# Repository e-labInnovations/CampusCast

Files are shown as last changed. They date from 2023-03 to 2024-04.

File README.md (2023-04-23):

<p align="center">
  <a href="http://campuscast.elabins.com/">
    CampusCast Logo
  </a>
</p>

<p align="justify">
CampusCast is an IoT-based announcement system designed to improve communication within academic institutions. The system consists of hardware and software components, including a microcontroller, digital-to-analogue converter, power amplifier, acknowledgement button, backend IoT server, WebSocket technology, and mobile app. With CampusCast, teachers and authorities can send voice announcements with customizable routes to specific classrooms, branches, years, or classes, ensuring every message is received and acknowledged. The system also includes features such as Smart Notifications and Exam Time Alerts to provide targeted and timely communication without disrupting class activities. CampusCast aims to modernize the communication system in colleges and universities, enhance the campus experience for everyone involved, and improve student engagement and academic success.
</p>

- [CampusCast Mobile APP](https://github.com/e-labInnovations/CampusCast-app)
- [CampusCast Server](https://github.com/e-labInnovations/CampusCast-server)

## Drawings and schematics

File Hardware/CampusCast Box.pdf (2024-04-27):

# CampusCast CampusCast

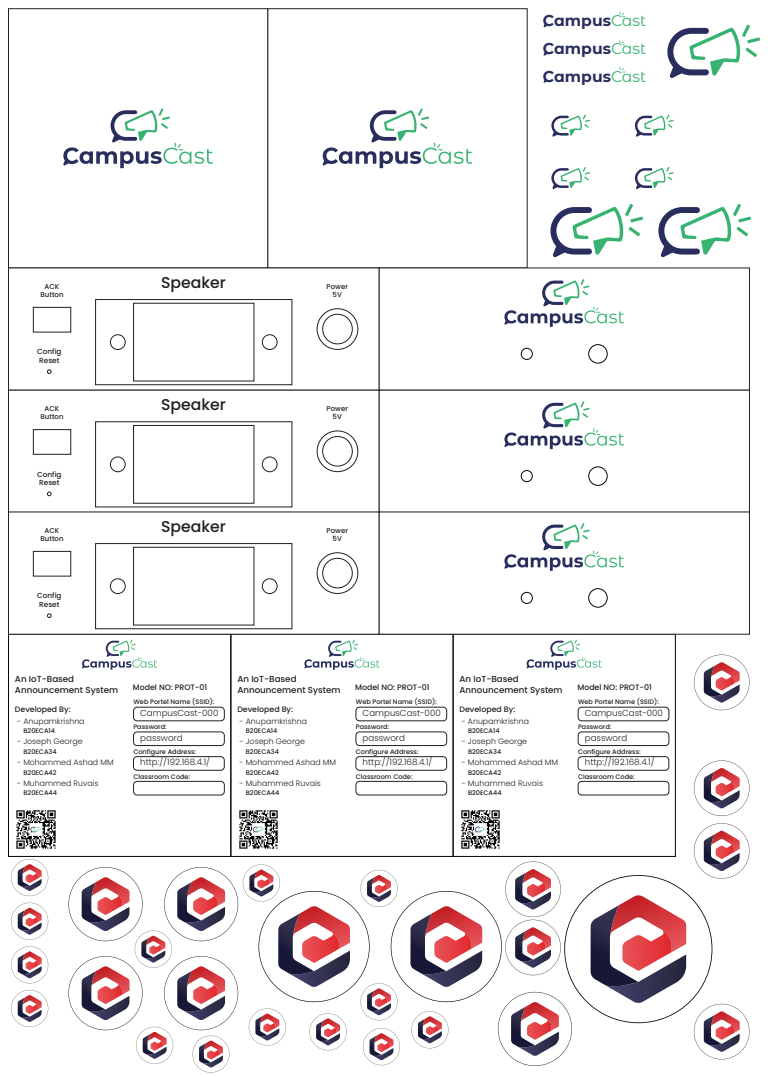
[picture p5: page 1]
Config Reset; ACK; Speaker Button; Power 5V; CampusCast; Developed By: - Anupamkrishna B20ECA14 - Joseph George B20ECA34 - Mohammed Ashad MM B20ECA42 - Muhammed Ruvais B20ECA44; An IoT-Based Announcement System

Model NO: PROT-01
Web Portel Name (SSID):
CampusCast-000
Password:
password
Configure Address:
http://192.168.4.1/
Classroom Code:

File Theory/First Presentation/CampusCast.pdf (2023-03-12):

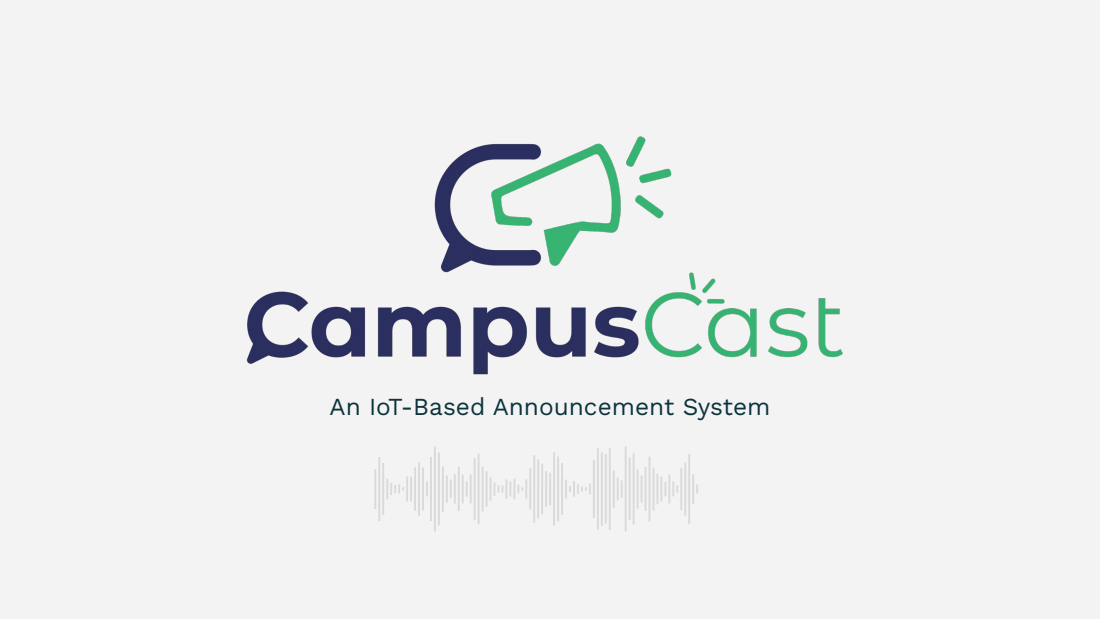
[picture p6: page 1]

An IoT-Based Announcement System

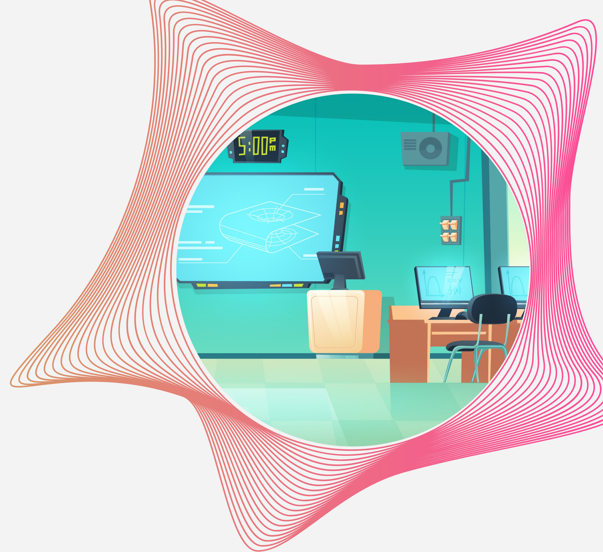
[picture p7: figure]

Welcome to CampusCast, an IoT-based announcement system that offers a modern and efficient solution for communication within academic institutions. With this system, college authorities can easily send voice announcements with customizable routes to specific classrooms, branches, years, or classes. CampusCast helps save time and resources by providing a targeted and timely communication channel, while also keeping students and faculty informed about important updates and events.

# Introduction

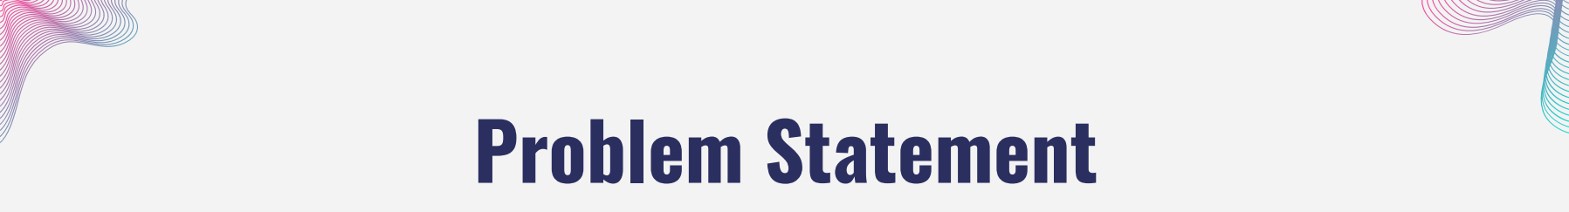
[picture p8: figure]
Problem Statement

1. In many colleges, teachers send announcements or important messages through WhatsApp groups while students are attending classes. However, it can be difficult for students to check their smartphones and receive timely notifications while in class.
2. Some students rely on hostel WiFi to access WhatsApp messages, but many colleges do not provide WiFi on campus, making it challenging for students to stay connected and receive important updates.
3. During exams, the bell system often favors regular classes, leaving students taking exams without proper time alerts. Even if they have smartwatches, these devices are not allowed in classrooms.

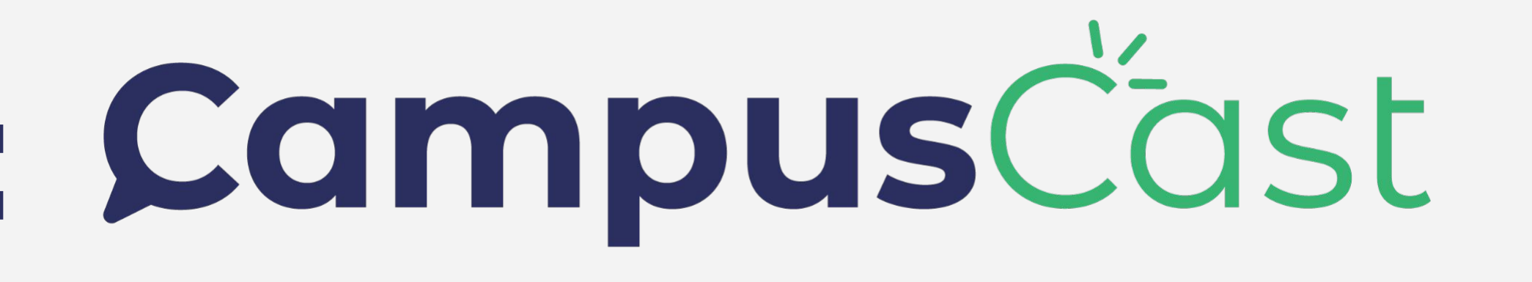
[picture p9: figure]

# Our Solution:

Revolutionizing Campus Communication

- CampusCast is an IoT-based announcement system that revolutionizes campus communication by providing a smart and efficient way for teachers and students to stay connected.
- With CampusCast , teachers can send announcements, reminders, and important messages to students instantly through a centralized system that ensures every message is received and acknowledged.
- CampusCast provides a feature called "Smart Notification" that ensures students receive important messages at the right time, without interrupting their class activities. This feature allows students to receive notifications via a smart speaker, without having to check their smartphones.

# Our Solution:

Revolutionizing Campus Communication

- CampusCast also provides a feature called "Exam Time Alerts" that sends notifications to students attending exams, ensuring they are informed about exam times. This feature helps to eliminate the need for the traditional bell system, which can be disruptive to exam-taking students.
- With CampusCast, students can also receive messages and announcements even if they don't have access to Wi-Fi on campus. The system uses IoT technology that ensures messages are delivered with the acknowledgement.
- CampusCast is easy to use and user-friendly, allowing you to send announcements quickly and easily, similar to sending a snap on the Snapchat app.

# Hardware System

+=

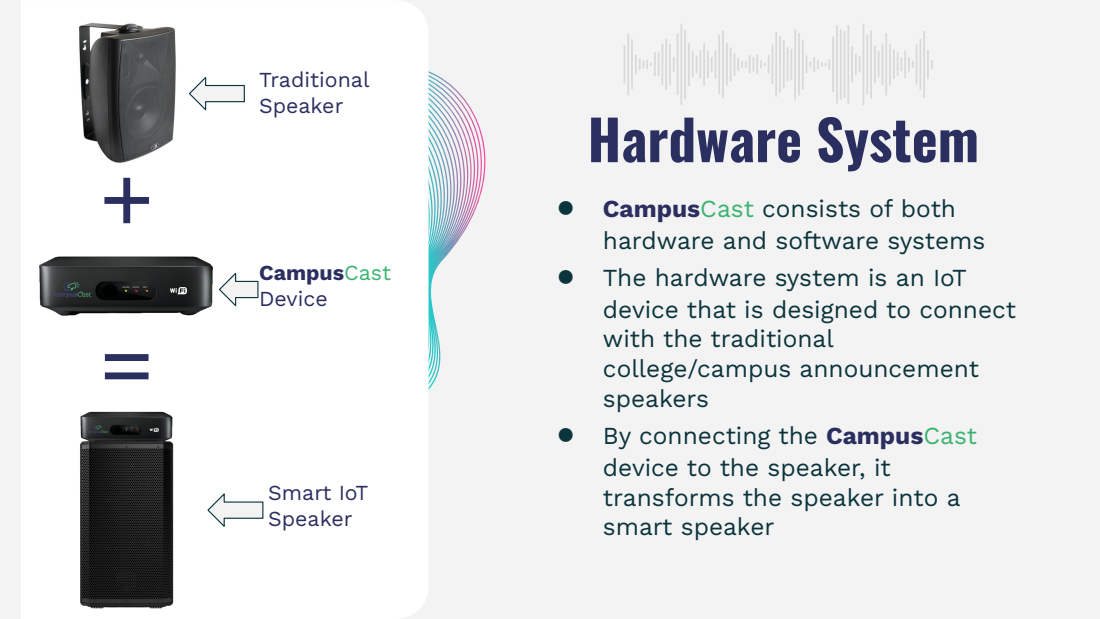
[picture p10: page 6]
Traditional Speaker; CampusCast Device; Smart IoT Speaker

● CampusCast consists of both
hardware and software systems
● The hardware system is an IoT
device that is designed to connect
with the traditional
college/campus announcement
speakers
● By connecting the CampusCast
device to the speaker, it
transforms the speaker into a
smart speaker

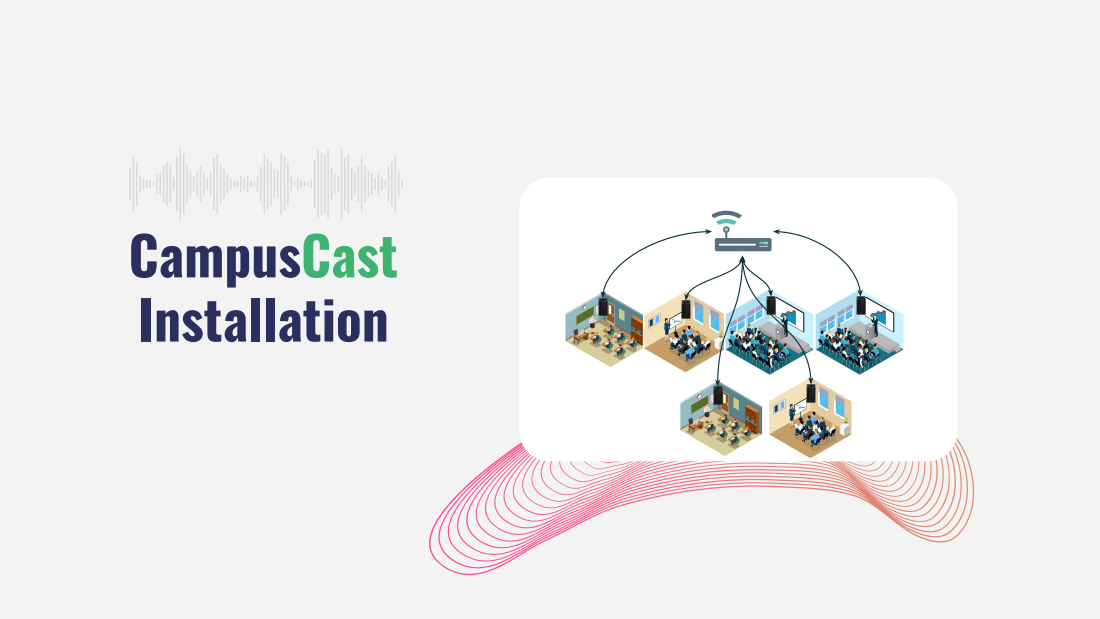
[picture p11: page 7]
CampusCast Installation

# CampusCast System Architecture

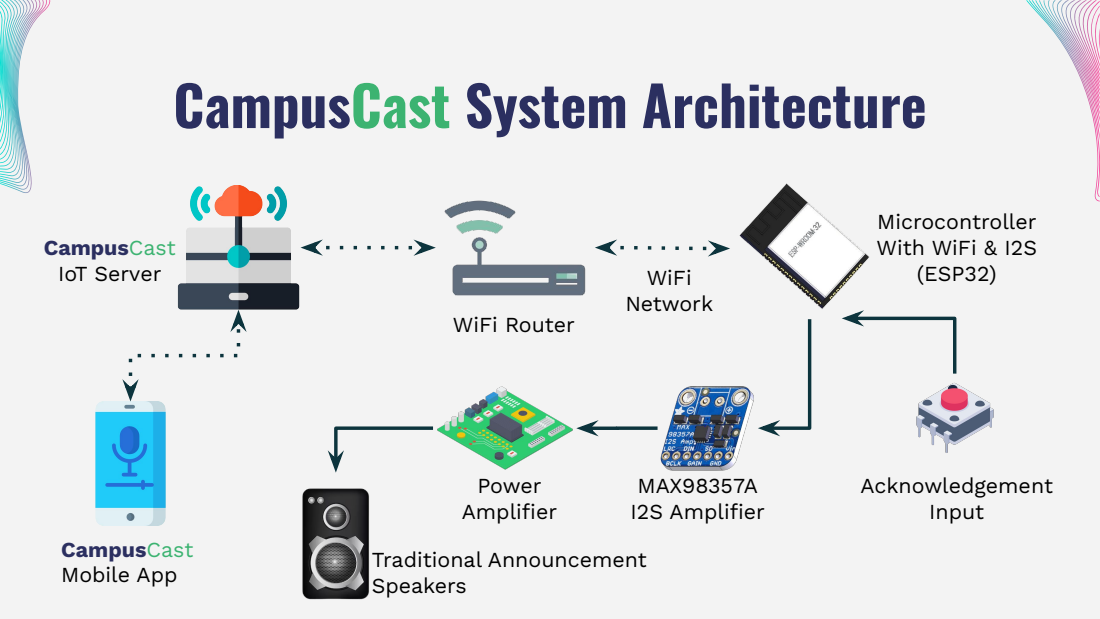
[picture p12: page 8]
Traditional Announcement Speakers; CampusCast Mobile App; Power Amplifier; MAX98357A I2S Amplifier; Acknowledgement Input; WiFi Router; IoT Server; WiFi; Network

Microcontroller With WiFi & I2S | (ESP32)

CampusCast

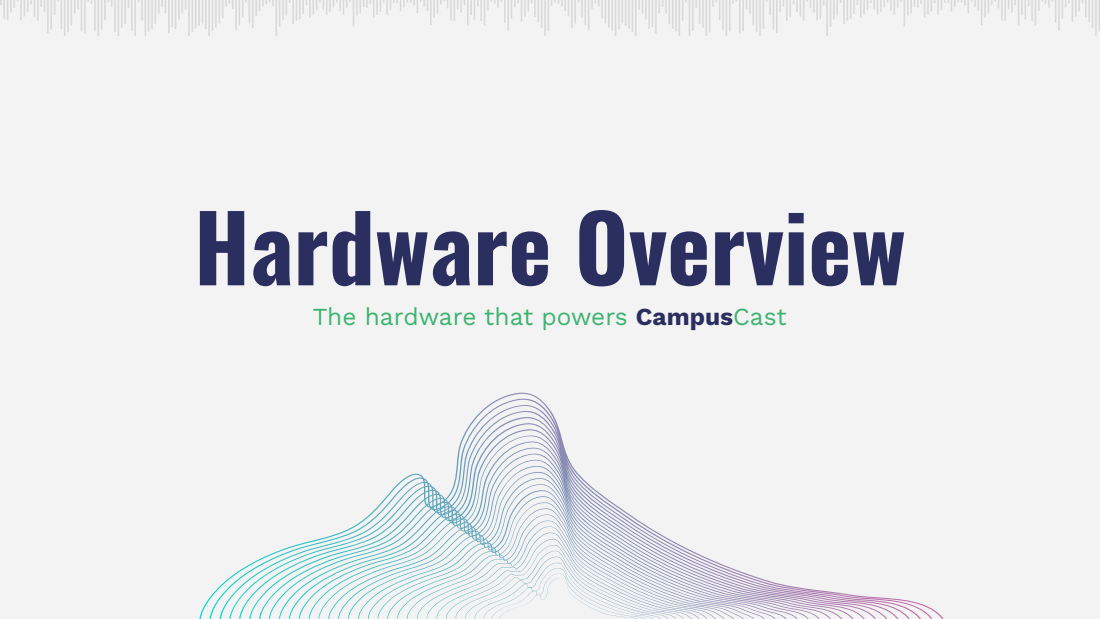
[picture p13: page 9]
Hardware Overview

The hardware that powers CampusCast

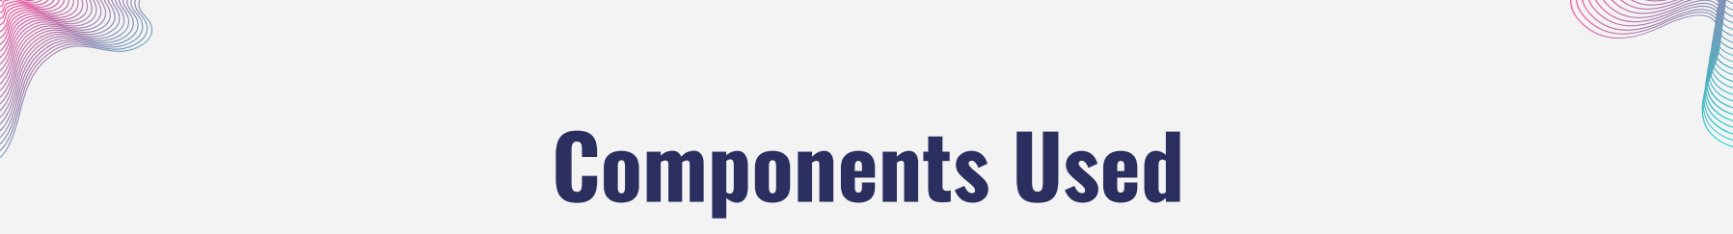
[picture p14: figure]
Components Used

1. ESP32: A powerful microcontroller that serves as the brain of the CampusCast system.
2. MAX98357A I2S Amplifier: A digital-to-analog converter that converts the audio signals from the ESP32 into an analog signal.
3. Class D Power Amplifier: An amplifier that amplifies the analog signal from the MAX98357A and provides enough power to drive the college wall mount speakers.
4. Acknowledgement Button: A button that allows the students to acknowledge that they have received a message or announcement. This helps ensure that important information is not missed.

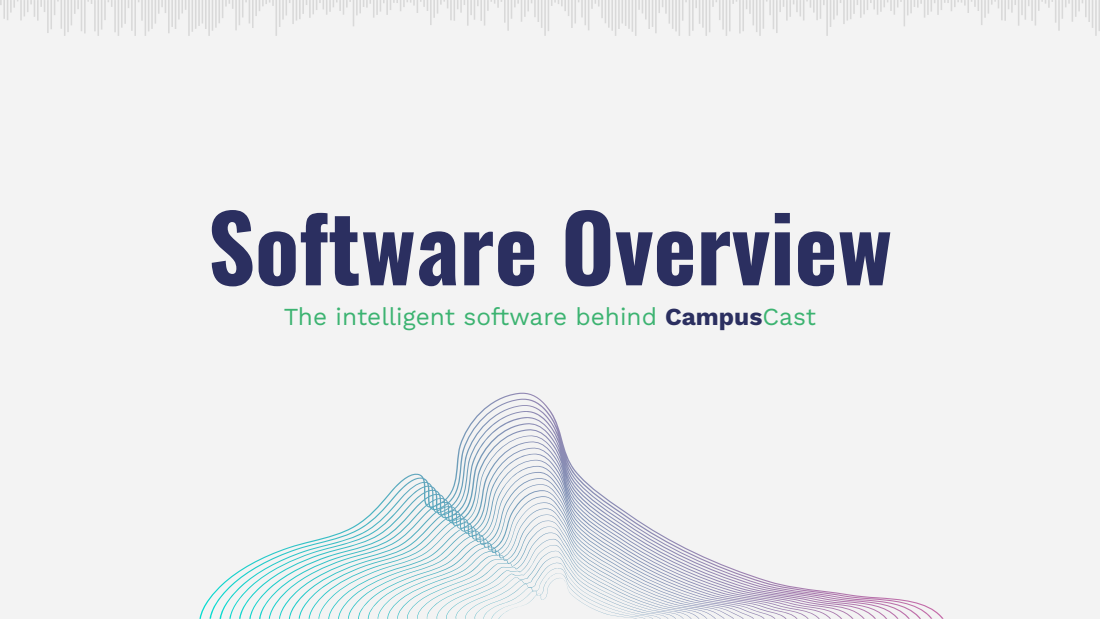
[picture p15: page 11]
Software Overview

The intelligent software behind CampusCast

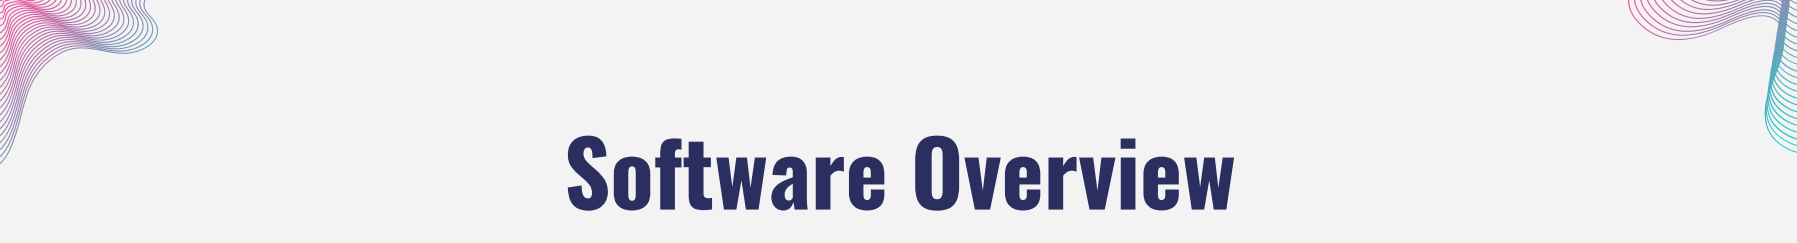
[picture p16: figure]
Software Overview

1. Backend IoT server: Planning to use Node-RED or Node.js for the backend IoT server that will handle the communication between the CampusCast devices and the mobile app.
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






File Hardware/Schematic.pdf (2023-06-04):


Drawn By: Mohammed Ashad

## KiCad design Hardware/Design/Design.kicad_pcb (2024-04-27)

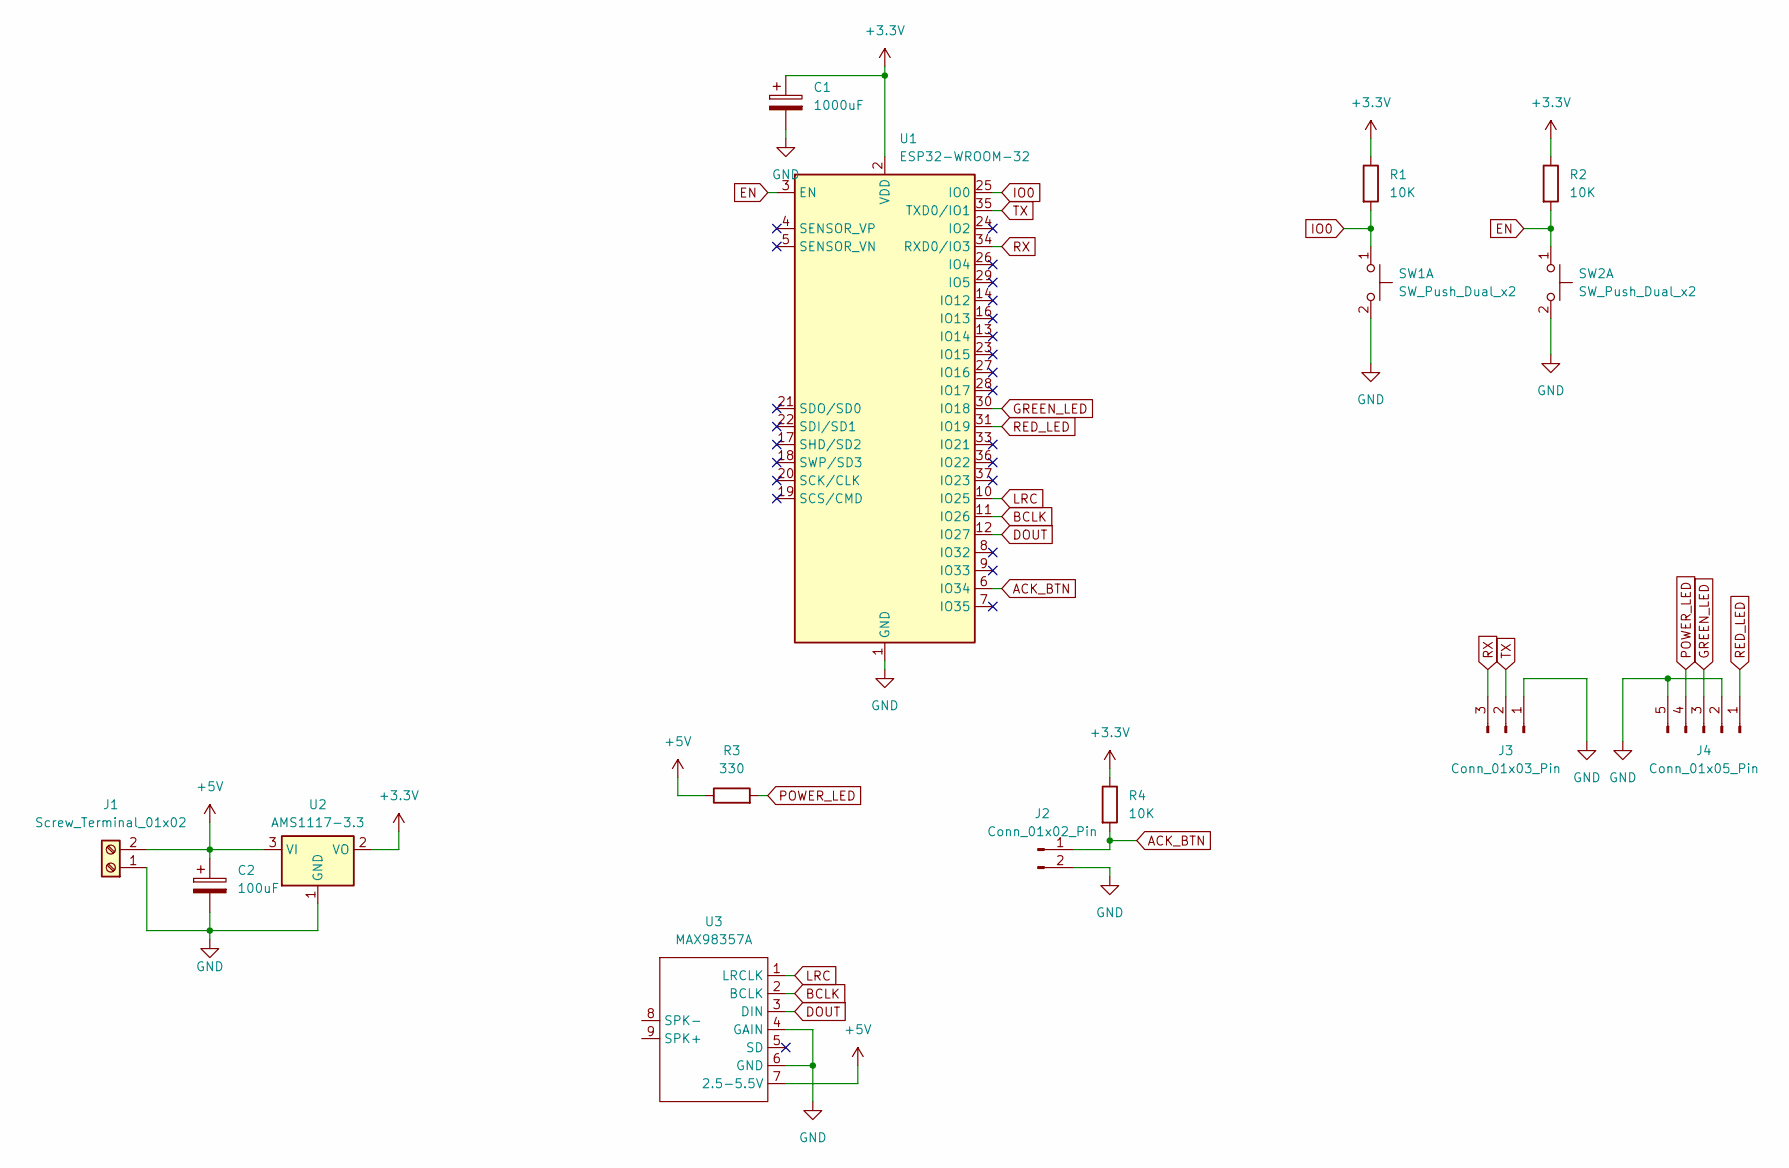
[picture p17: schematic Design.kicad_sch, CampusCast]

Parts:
C1: 1000uF; CP_Radial_D8.0mm_P5.00mm
C2: 100uF; CP_Radial_D5.0mm_P2.00mm
J1: Screw_Terminal_01x02; TerminalBlock_Phoenix_MKDS-1,5-2-5.08_1x02_P5.08mm_Horizont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
J2: Conn_01x02_Pin; PinHeader_1x02_P2.54mm_Vertical
J3: Conn_01x03_Pin; PinHeader_1x03_P2.54mm_Vertical
J4: Conn_01x05_Pin; PinHeader_1x05_P2.54mm_Vertical
R1, R2, R4: 10K; R_Axial_DIN0207_L6.3mm_D2.5mm_P7.62mm_Horizontal
R3: 330; R_Axial_DIN0207_L6.3mm_D2.5mm_P7.62mm_Horizontal
SW1, SW2: SW_Push_Dual_x2; SW_PUSH_6mm_H7.3mm
U1: ESP32-WROOM-32; ESP32-WROOM-32_MOD
U2: AMS1117-3.3; SOT-223-3_TabPin2
U3: MAX98357A

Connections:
+3.3V: C1.1, R1.1, R2.1, R4.1, U1.2 (VDD), U2.2 (VO)
+5V: C2.1, J1.2, R3.1, U2.3 (VI), U3.7 (2.5-5.5V)
ACK_BTN: J2.1, R4.2, U1.6 (IO34)
BCLK: U1.11 (IO26), U3.2 (BCLK)
DOUT: U1.12 (IO27), U3.3 (DIN)
EN: R2.2, SW2.1 (C), U1.3 (EN)
GND: C1.2, C2.2, J1.1, J2.2, J3.1, J4.2, J4.5, SW1.2 (D), SW2.2 (D), U1.1 (GND), U1.15 (GND), U1.38 (GND), U1.39 (GND), U2.1 (GND), U3.4 (GAIN), U3.6 (GND)
GREEN_LED: J4.3, U1.30 (IO18)
IO0: R1.2, SW1.1 (C), U1.25 (IO0)
LRC: U1.10 (IO25), U3.1 (LRCLK)
POWER_LED: J4.4, R3.2
RED_LED: J4.1, U1.31 (IO19)
RX: J3.3, U1.34 (RXD0/IO3)
TX: J3.2, U1.35 (TXD0/IO1)

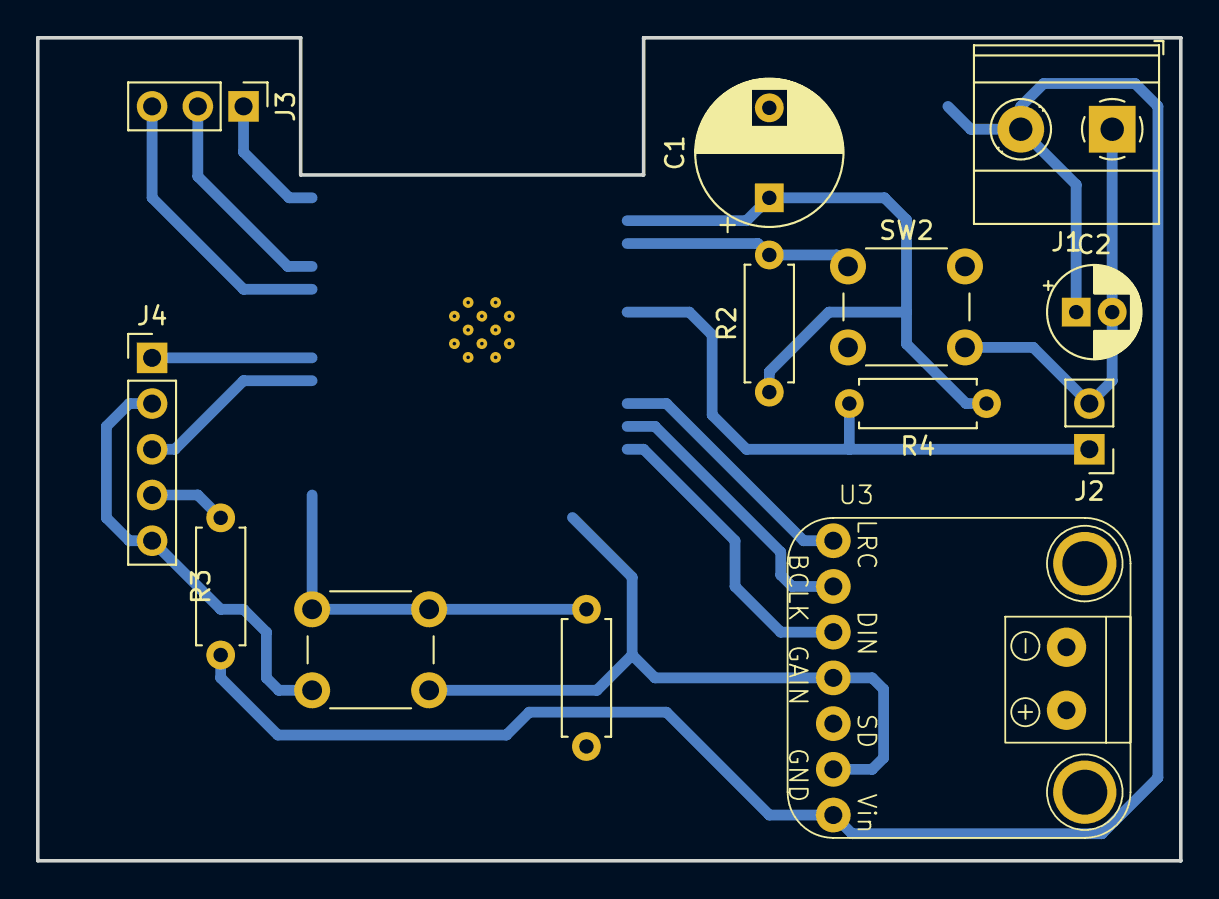
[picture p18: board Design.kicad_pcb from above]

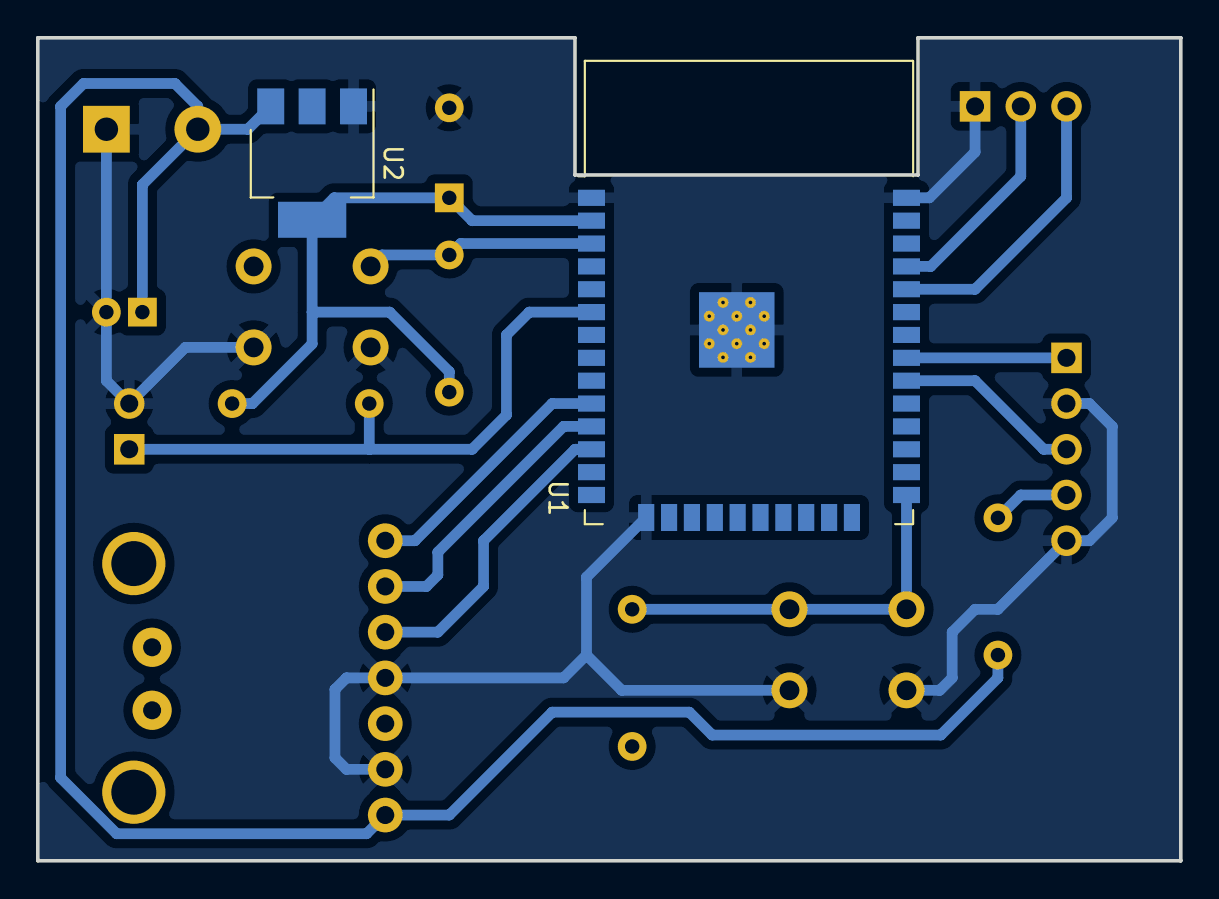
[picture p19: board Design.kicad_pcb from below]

Board: 2 copper layers, 63.5 x 45.7 mm, 15 parts (2 on the bottom side), 14 nets.

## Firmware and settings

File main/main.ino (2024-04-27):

#include <FS.h>  // this needs to be first, or it all crashes and burns...
#include <SPIFFS.h>
#include "./src/WiFiManager/WiFiManager.h"
#include <ArduinoJson.h>       // https://github.com/bblanchon/ArduinoJson
#include <WebSocketsClient.h>  //version 2.3.6
#include "WiFi.h"
#include "Audio.h"
/*
ESP32 Board             => 2.0.13
FS                      => 2.0.0  
SPIFFS                  => 2.0.0
WiFi                    => 2.0.0
Update                  => 2.0.0
WebServer               => 2.0.0
DNSServer               => 2.0.0
ArduinoJson             => 6.20.1 
WebSockets              => 2.3.6
WiFiClientSecure        => 2.0.0
ESP32-audioI2S-master   => 2.0.0
SPI                     => 2.0.0
SD                      => 2.0.0
SD_MMC                  => 2.0.0
FFat                    => 2.0.0
*/

#define SSID_PREFIX "CampusCast_"
#define PASSWORD "password"
#define JSON_CONFIG_FILE "/config.json"

#define I2S_DOUT 27
#define I2S_BCLK 26
#define I2S_LRC 25
#define BTN_CONFIG_RESET 0
#define BTN_ACK 34
#define RED_LED 19
#define GREEN_LED 18

Audio audio;
WiFiManager wm;
WebSocketsClient webSocket;

bool shouldSaveConfig = true;
char classroom_code_val[10] = "000";
char ws_server_val[21] = "192.168.x.x";
int ws_server_port_val = 1880;
char ws_server_path_val[41] = "/";

bool playAudio = false;
String audioURL = "";
String anncmntId = "";
bool prevAckStatus = true;
String introURL = "";
String outroURL = "";
int audioStatus = 0;
String audioType = "";

enum IndicatorStatus {
  START_MODE,
  CONFIG_MODE,
  WIFI_NOT_CONN,
  WIFI_CONN_SRV_NOT_CONN,
  WIFI_SRV_OK
};

struct Indicator {
  int redLedOldStatus;
  int greenLedOldStatus;
  IndicatorStatus currentStatus;
  unsigned long previousMillis;
};
Indicator indicator;


void setup() {
  Serial.begin(115200);
  Serial.setDebugOutput(true);

  audio.setPinout(I2S_BCLK, I2S_LRC, I2S_DOUT);
  audio.setVolume(21);

  pinMode(BTN_CONFIG_RESET, INPUT);
  pinMode(BTN_ACK, INPUT);

  pinMode(RED_LED, OUTPUT);
  pinMode(GREEN_LED, OUTPUT);

  // Initialize the Indicator structure
  indicator.redLedOldStatus = LOW;
  indicator.greenLedOldStatus = LOW;
  indicator.currentStatus = START_MODE;
  indicator.previousMillis = 0;
  setIndicatorStatus(START_MODE);

  bool forceConfig = false;  // Change to true when testing to force configuration every time we run

  bool spiffsSetup = loadConfigFile();
  if (!spiffsSetup) {
    Serial.println(F("Forcing config mode as there is no saved config"));
    forceConfig = true;
  }

  setIndicatorStatus(WIFI_NOT_CONN);

  WiFi.mode(WIFI_STA);  // explicitly set mode, esp defaults to STA+AP
  setupWiFiManager();

  // server address, port and URL
  webSocket.begin(ws_server_val, ws_server_port_val, ws_server_path_val);
  // event handler
  webSocket.onEvent(webSocketEvent);
  // try ever 5000 again if connection has failed
  webSocket.setReconnectInterval(5000);
  // start heartbeat (optional)
  // ping server every 15000 ms
  // expect pong from server within 3000 ms
  // consider connection disconnected if pong is not received 2 times
  // webSocket.enableHeartbeat(15000, 3000, 2);

  Serial.print("WS server: ");
  Serial.println(ws_server_val);
  Serial.print("WS server port: ");
  Serial.println(ws_server_port_val);
  Serial.print("WS server path: ");
  Serial.println(ws_server_path_val);
  Serial.print("Classroom Code: ");
  Serial.println(classroom_code_val);
}

void loop() {
  webSocket.loop();
  audio.loop();

  // Update indicator LED
  if (WiFi.status() == WL_CONNECTED) {
    if (webSocket.isConnected()) {
      setIndicatorStatus(WIFI_SRV_OK);
    } else {
      setIndicatorStatus(WIFI_CONN_SRV_NOT_CONN);
    }
  } else {
    setIndicatorStatus(WIFI_NOT_CONN);
  }

  if (playAudio) {
    Serial.print("audioUrl: ");
    Serial.println(audioURL);
    Serial.print("Id: ");
    Serial.println(anncmntId);
    webSocket.disconnect();
    audio.connecttohost(introURL.c_str());
    playAudio = false;
    audioStatus = 0;
  }

  if (!digitalRead(BTN_CONFIG_RESET)) {
    Serial.println("BTN_CONFIG_RESET pressed, resetting WiFi credentials");
    wm.resetSettings();  // reset settings - wipe stored credentials for testing
    ESP.restart();       // restart eps32
  }

  bool presAckStatus = digitalRead(BTN_ACK);
  if (prevAckStatus && !presAckStatus) {
    Serial.println("BTN_ACK pressed");

    if (anncmntId != "") {
      webSocket.sendTXT("{ \"command\":\"ack\", \"classroom_code\": \"" + String(classroom_code_val) + "\", \"msg_id\":\"" + anncmntId + "\" }");
      anncmntId = "";
    }
    delay(10);
  }
  prevAckStatus = presAckStatus;
}

void handleIncomingData(uint8_t *json) {
  DynamicJsonDocument recvData(500);
  DeserializationError error = deserializeJson(recvData, json);

  if (error) {
    Serial.print("deserializeJson() failed: ");
    Serial.println(error.f_str());
    return;
  }

  String command = recvData["command"];
  Serial.println(command);

  if (command == "connected_ack") {
    const char *_introURL = recvData["introURL"];
    const char *_outroURL = recvData["outroURL"];
    introURL = String(_introURL);
    outroURL = String(_outroURL);
  } else if (command == "anncmnt") {
    String recipient = recvData["recipient"];
    if (recipient == String(classroom_code_val)) {
      const char *_audioURL = recvData["audioUrl"];
      const char *_anncmntId = recvData["id"];
      audioURL = String(_audioURL);
      anncmntId = String(_anncmntId);
      playAudio = true;
      audioType = "anncmnt";
      webSocket.sendTXT("{ \"command\":\"ack_received\", \"classroom_code\": \"" + String(classroom_code_val) + "\", \"msg_id\":\"" + anncmntId + "\" }");
    }
  } else if (command == "examschedule") {
    String recipient = recvData["recipient"];
    if (recipient == String(classroom_code_val)) {
      const char *_audioURL = recvData["audioUrl"];
      audioURL = String(ws_server_val) + ":" + String(ws_server_port_val) + "/examschedule?id=" + String(_audioURL);
      playAudio = true;
      audioType = "notification";
    }
  }
}

void webSocketEvent(WStype_t type, uint8_t *payload, size_t length) {
  switch (type) {
    case WStype_DISCONNECTED:
      Serial.printf("[WSc] Disconnected!\n");
      break;
    case WStype_CONNECTED:
      Serial.printf("[WSc] Connected to url: %s\n", payload);

      // send message to server when Connected
      webSocket.sendTXT("{ \"command\":\"connected\", \"classroom_code\": \"" + String(classroom_code_val) + "\" }");
      break;
    case WStype_TEXT:
      Serial.printf("[WSc] get text: %s\n", payload);

      handleIncomingData(payload);
      break;
  }
}

void saveConfigFile() {
  Serial.println(F("Saving configuration..."));

  // Create a JSON document
  StaticJsonDocument<512> json;
  json["ws_server"] = ws_server_val;
  json["ws_server_port"] = ws_server_port_val;
  json["ws_server_path"] = ws_server_path_val;
  json["classroom_code"] = classroom_code_val;

  // Open config file
  File configFile = SPIFFS.open(JSON_CONFIG_FILE, "w");
  if (!configFile) {
    Serial.println("failed to open config file for writing");
  }

  // Serialize JSON data to write to file
  serializeJsonPretty(json, Serial);
  if (serializeJson(json, configFile) == 0) {
    Serial.println(F("Failed to write to file"));
  }
  // Close file
  configFile.close();
}

// Load existing configuration file
bool loadConfigFile() {
  // Uncomment if we need to format filesystem
  // SPIFFS.format();

  // Read configuration from FS json
  Serial.println("Mounting File System...");

  // May need to make it begin(true) first time you are using SPIFFS
  if (SPIFFS.begin(true)) {
    Serial.println("mounted file system");
    if (SPIFFS.exists(JSON_CONFIG_FILE)) {
      // The file exists, reading and loading
      Serial.println("reading config file");
      File configFile = SPIFFS.open(JSON_CONFIG_FILE, "r");
      if (configFile) {
        Serial.println("Opened configuration file");
        StaticJsonDocument<512> json;
        DeserializationError error = deserializeJson(json, configFile);
        serializeJsonPretty(json, Serial);
        if (!error) {
          Serial.println("Parsing JSON");

          strcpy(ws_server_val, json["ws_server"]);
          ws_server_port_val = json["ws_server_port"].as<int>();
          strcpy(ws_server_path_val, json["ws_server_path"]);
          strcpy(classroom_code_val, json["classroom_code"]);
          return true;
        } else {
          // Error loading JSON data
          Serial.println("Failed to load json config");
        }
      }
    }
  } else {
    // Error mounting file system
    Serial.println("Failed to mount FS");
  }
  return false;
}

// Callback notifying us of the need to save configuration
void saveConfigCallback() {
  Serial.println("Should save config");
  shouldSaveConfig = true;
}

// Called when config mode launched
void configModeCallback(WiFiManager *myWiFiManager) {
  setIndicatorStatus(CONFIG_MODE);
  Serial.println("Entered Configuration Mode");

  Serial.print("Config SSID: ");
  Serial.println(myWiFiManager->getConfigPortalSSID());

  Serial.print("Config IP Address: ");
  Serial.println(WiFi.softAPIP());
}


void setupWiFiManager() {
  // wm.resetSettings(); // reset settings - wipe stored credentials for testing
  wm.setSaveConfigCallback(saveConfigCallback);  // Set config save notify callback
  wm.setAPCallback(configModeCallback);          // Set callback that gets called when connecting to previous WiFi fails, and enters Access Point mode
  wm.setDebugOutput(false);                      //Disable debugging
  wm.setDarkMode(true);                          // dark theme

  WiFiManagerParameter ws_server("ws_server", "Websocket Server Address", ws_server_val, 20);
  wm.addParameter(&ws_server);

  char ws_server_port_val_a[16];
  WiFiManagerParameter ws_server_port("ws_server_port", "Websocket Server Port", itoa(ws_server_port_val, ws_server_port_val_a, 10), 5);
  wm.addParameter(&ws_server_port);

  WiFiManagerParameter ws_server_path("ws_server_path", "Websocket Server Path", ws_server_path_val, 40);
  wm.addParameter(&ws_server_path);

  WiFiManagerParameter classroom_code("classroom_code", "Classroom No", classroom_code_val, 10);
  wm.addParameter(&classroom_code);

  bool res;
  String AP_NAME = SSID_PREFIX + String(classroom_code_val);
  res = wm.autoConnect(AP_NAME.c_str(), PASSWORD);  // password protected ap

  if (!res) {
    Serial.println("Failed to connect");
    ESP.restart();
  }

  setIndicatorStatus(WIFI_CONN_SRV_NOT_CONN);
  Serial.println("");
  Serial.println("WiFi connected");
  Serial.print("IP address: ");
  Serial.println(WiFi.localIP());


  strncpy(ws_server_val, ws_server.getValue(), sizeof(ws_server_val));                 // Copy the string value
  ws_server_port_val = atoi(ws_server_port.getValue());                                //Convert the number value
  strncpy(ws_server_path_val, ws_server_path.getValue(), sizeof(ws_server_path_val));  // Copy the string value
  strcpy(classroom_code_val, classroom_code.getValue());

  Serial.print("WS server: ");
  Serial.println(ws_server.getValue());
  Serial.print("WS server port: ");
  Serial.println(ws_server_port.getValue());
  Serial.print("WS server path: ");
  Serial.println(ws_server_path.getValue());
  Serial.print("Classroom Code: ");
  Serial.println(classroom_code.getValue());
  // Save the custom parameters to FS
  if (shouldSaveConfig) {
    saveConfigFile();
  }
}

void setIndicatorStatus(IndicatorStatus status) {
  unsigned long currentMillis = millis();
  switch (status) {
    case START_MODE:
      indicator.redLedOldStatus = LOW;
      indicator.greenLedOldStatus = LOW;
      digitalWrite(RED_LED, indicator.redLedOldStatus);
      digitalWrite(GREEN_LED, indicator.greenLedOldStatus);
      break;

    case CONFIG_MODE:
      // Set RED LED ON
      indicator.redLedOldStatus = HIGH;
      indicator.greenLedOldStatus = LOW;
      digitalWrite(RED_LED, indicator.redLedOldStatus);
      digitalWrite(GREEN_LED, indicator.greenLedOldStatus);
      break;

    case WIFI_NOT_CONN:
      // Set RED LED BLINKING
      if (currentMillis - indicator.previousMillis >= 500) {
        indicator.previousMillis = currentMillis;

        indicator.redLedOldStatus = !indicator.redLedOldStatus;
        indicator.greenLedOldStatus = LOW;
        digitalWrite(RED_LED, indicator.redLedOldStatus);
        digitalWrite(GREEN_LED, indicator.greenLedOldStatus);
      }
      break;

    case WIFI_CONN_SRV_NOT_CONN:
      // Alternately turn on and off red and green LEDs
      if (currentMillis - indicator.previousMillis >= 500) {
        indicator.previousMillis = currentMillis;

        indicator.redLedOldStatus = !indicator.redLedOldStatus;
        indicator.greenLedOldStatus = !indicator.redLedOldStatus;
        digitalWrite(RED_LED, indicator.redLedOldStatus);
        digitalWrite(GREEN_LED, indicator.greenLedOldStatus);
      }
      break;

    case WIFI_SRV_OK:
      // Set GREEN LED ON
      indicator.redLedOldStatus = LOW;
      indicator.greenLedOldStatus = HIGH;
      digitalWrite(RED_LED, indicator.redLedOldStatus);
      digitalWrite(GREEN_LED, indicator.greenLedOldStatus);
      break;
  }
}

//
void audio_info(const char *info) {
  Serial.print("info        ");
  Serial.println(info);
  if (strstr(info, "End of webstream") != NULL) {
    Serial.println("announcement completed");
    if (audioStatus == 0 || audioStatus == 1) {
      audio.connecttohost(audioURL.c_str());
      audioStatus++;
    } else if (audioStatus == 2) {
      if (audioType == "notification") {
        audioStatus += 1;
      } else {
        audio.connecttohost(outroURL.c_str());
        audioStatus += 1;
      }
    }
  }
}

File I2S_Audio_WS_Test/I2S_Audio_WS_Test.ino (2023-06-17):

#include "WiFi.h"
#include "Audio.h"
#include <WiFiManager.h>       // https://github.com/tzapu/WiFiManager
#include <WebSocketsClient.h>  //version 2.3.6

#define I2S_DOUT 27
#define I2S_BCLK 26
#define I2S_LRC 25

// const char* ssid = "e-labinnovations";
// const char* password = "PASSWORD";

Audio audio;
WiFiManager wm;
WebSocketsClient webSocket;

char *audioURL;
bool playAudio = false;

void setup() {
  Serial.begin(115200);
  Serial.setDebugOutput(true);

  audio.setPinout(I2S_BCLK, I2S_LRC, I2S_DOUT);
  audio.setVolume(21);

  bool res;
  // res = wm.autoConnect(); // auto generated AP name from chipid
  // res = wm.autoConnect("CampusCast"); // anonymous ap
  res = wm.autoConnect("CampusCast", "password");  // password protected ap

  if (!res) {
    Serial.println("Failed to connect");
    // ESP.restart();
  } else {
    //if you get here you have connected to the WiFi
    Serial.println("connected...yeey :)");
  }


  // server address, port and URL
  webSocket.begin("192.168.29.69", 1880, "/");
  // event handler
  webSocket.onEvent(webSocketEvent);
  // try ever 5000 again if connection has failed
  webSocket.setReconnectInterval(5000);
  // start heartbeat (optional)
  // ping server every 15000 ms
  // expect pong from server within 3000 ms
  // consider connection disconnected if pong is not received 2 times
  // webSocket.enableHeartbeat(15000, 3000, 2);

  // audio.connecttohost("http://vis.media-ice.musicradio.com/CapitalMP3");
  // audio.connecttohost("https://firebasestorage.googleapis.com/v0/b/campuscast-elabins.appspot.com/o/recording-test01.m4a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");
  // playAudio = true;
}

void loop() {
  webSocket.loop();
  audio.loop();

  if (playAudio) {
    // audio.connecttohost(audioURL);
    // webSocket.disconnect();
    // audio.connecttohost("https://github.com/schreibfaul1/ESP32-audioI2S/raw/master/additional_info/Testfiles/Olsen-Banden.mp3");
    audio.connecttohost("https://firebasestorage.googleapis.com/v0/b/campuscast-elabins.appspot.com/o/recording-test01.m4a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");
    // audio.connecttospeech("New announcement received", "en");
    playAudio = false;
  }
}


void webSocketEvent(WStype_t type, uint8_t *payload, size_t length) {
  switch (type) {
    case WStype_DISCONNECTED:
      Serial.printf("[WSc] Disconnected!\n");
      break;
    case WStype_CONNECTED:
      Serial.printf("[WSc] Connected to url: %s\n", payload);

      // send message to server when Connected
      webSocket.sendTXT("{ \"command\":\"connected\", \"classroom_code\": \"236\" }");
      // audio.connecttospeech("Connected CampusCast server", "en");
      playAudio = true;
      break;
    case WStype_TEXT:
      Serial.printf("[WSc] get text: %s\n", payload);

      playAudio = true;
      break;
  }
}

// optional
void audio_info(const char *info) {
  Serial.print("info        ");
  Serial.println(info);
}
void audio_id3data(const char *info) {  //id3 metadata
  Serial.print("id3data     ");
  Serial.println(info);
}
void audio_eof_mp3(const char *info) {  //end of file
  Serial.print("eof_mp3     ");
  Serial.println(info);
}
void audio_showstation(const char *info) {
  Serial.print("station     ");
  Serial.println(info);
}
void audio_showstreamtitle(const char *info) {
  Serial.print("streamtitle ");
  Serial.println(info);
}
void audio_bitrate(const char *info) {
  Serial.print("bitrate     ");
  Serial.println(info);
}
void audio_commercial(const char *info) {  //duration in sec
  Serial.print("commercial  ");
  Serial.println(info);
}
void audio_icyurl(const char *info) {  //homepage
  Serial.print("icyurl      ");
  Serial.println(info);
}
void audio_lasthost(const char *info) {  //stream URL played
  Serial.print("lasthost    ");
  Serial.println(info);
}
void audio_eof_speech(const char *info) {
  Serial.print("eof_speech  ");
  Serial.println(info);
}

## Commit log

2023-04-17 New ESP32 code added
2023-06-04 PCB Design added
2023-06-17 M4A audio bug and connecttoserver stuck fixed
    [main.ino]
2023-06-18 only play right announcement, status led starting
2024-04-27 Hardware box stickers added
    [Design.kicad_pcb, Design.kicad_sch]
